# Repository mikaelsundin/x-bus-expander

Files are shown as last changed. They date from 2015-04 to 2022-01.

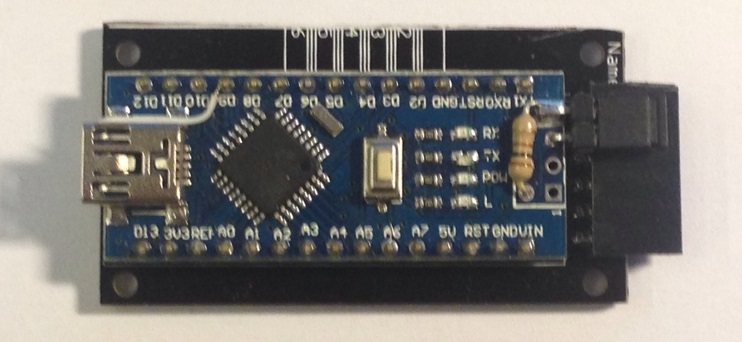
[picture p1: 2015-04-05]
cad/arduion-nano-with-modifications.jpg

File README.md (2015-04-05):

# x-bus-expander
Emulated Model Train digital interface for getting upto 64-inputs and 64-outputs.

Setup the interface
======
* Solder everything.
* Connect up to four boards in a chain.
* Modify dip switches so every board have a unique combination.
* Connect USB-cable to PC and install CH340G driver.

How to connect Inputs
======
Switches can be connected to IN1 or IN2, pull-up is located on-board. 
The input signals must be electrical isolated from the rest of the system to not dammage anything.
If other devices that switches will be connected a optocoupler is suggested to electrical isolate the input.
C1-C8, C10-C17 is to avoid interface from inputs.

How to connect Outputs
======
Led:s / lamps can be connected to OUT1 and OUT2. The output voltage is equal to the VIN voltage.
With 2N7002 the maximum load current is 115mA and suggested voltage shall be 24V DC or less on VIN.
Remember to use correct polarity on VIN, marked with + and - on PCB.

How to use the interface
======
If you are running Freiwald TrainController (www.freiwald.com)
 choose "Lenz Digital Plus / LI100(F)" and correct com-port.
 The outputs will be named with Address 1-64
 The inputs will be named with Address 1-8 and Input 1-8

Hardware modification to Arduino nano:
======
UART signal CTS is attached to D9 (easiest done to clones with CH340G USB chip).
A jumper with 120R resistor to disable auto-reset feature is also added.

Hardware
======
The hardware is adapted to fit a single 10x5cm board.
Suggested manufacture is iteadstudio.com or elecrow.com
The PCB must be separated into two parts after manufacture.
Use a hacksaw for example if PCB tickness is 1.6mm. 
If running at 1.2mm the PCB can acually be cut by a ordinary scissors (the scissors will loose sharpness).

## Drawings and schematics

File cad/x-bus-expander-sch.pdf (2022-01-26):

# 16 Input, 16 Sink Output

A

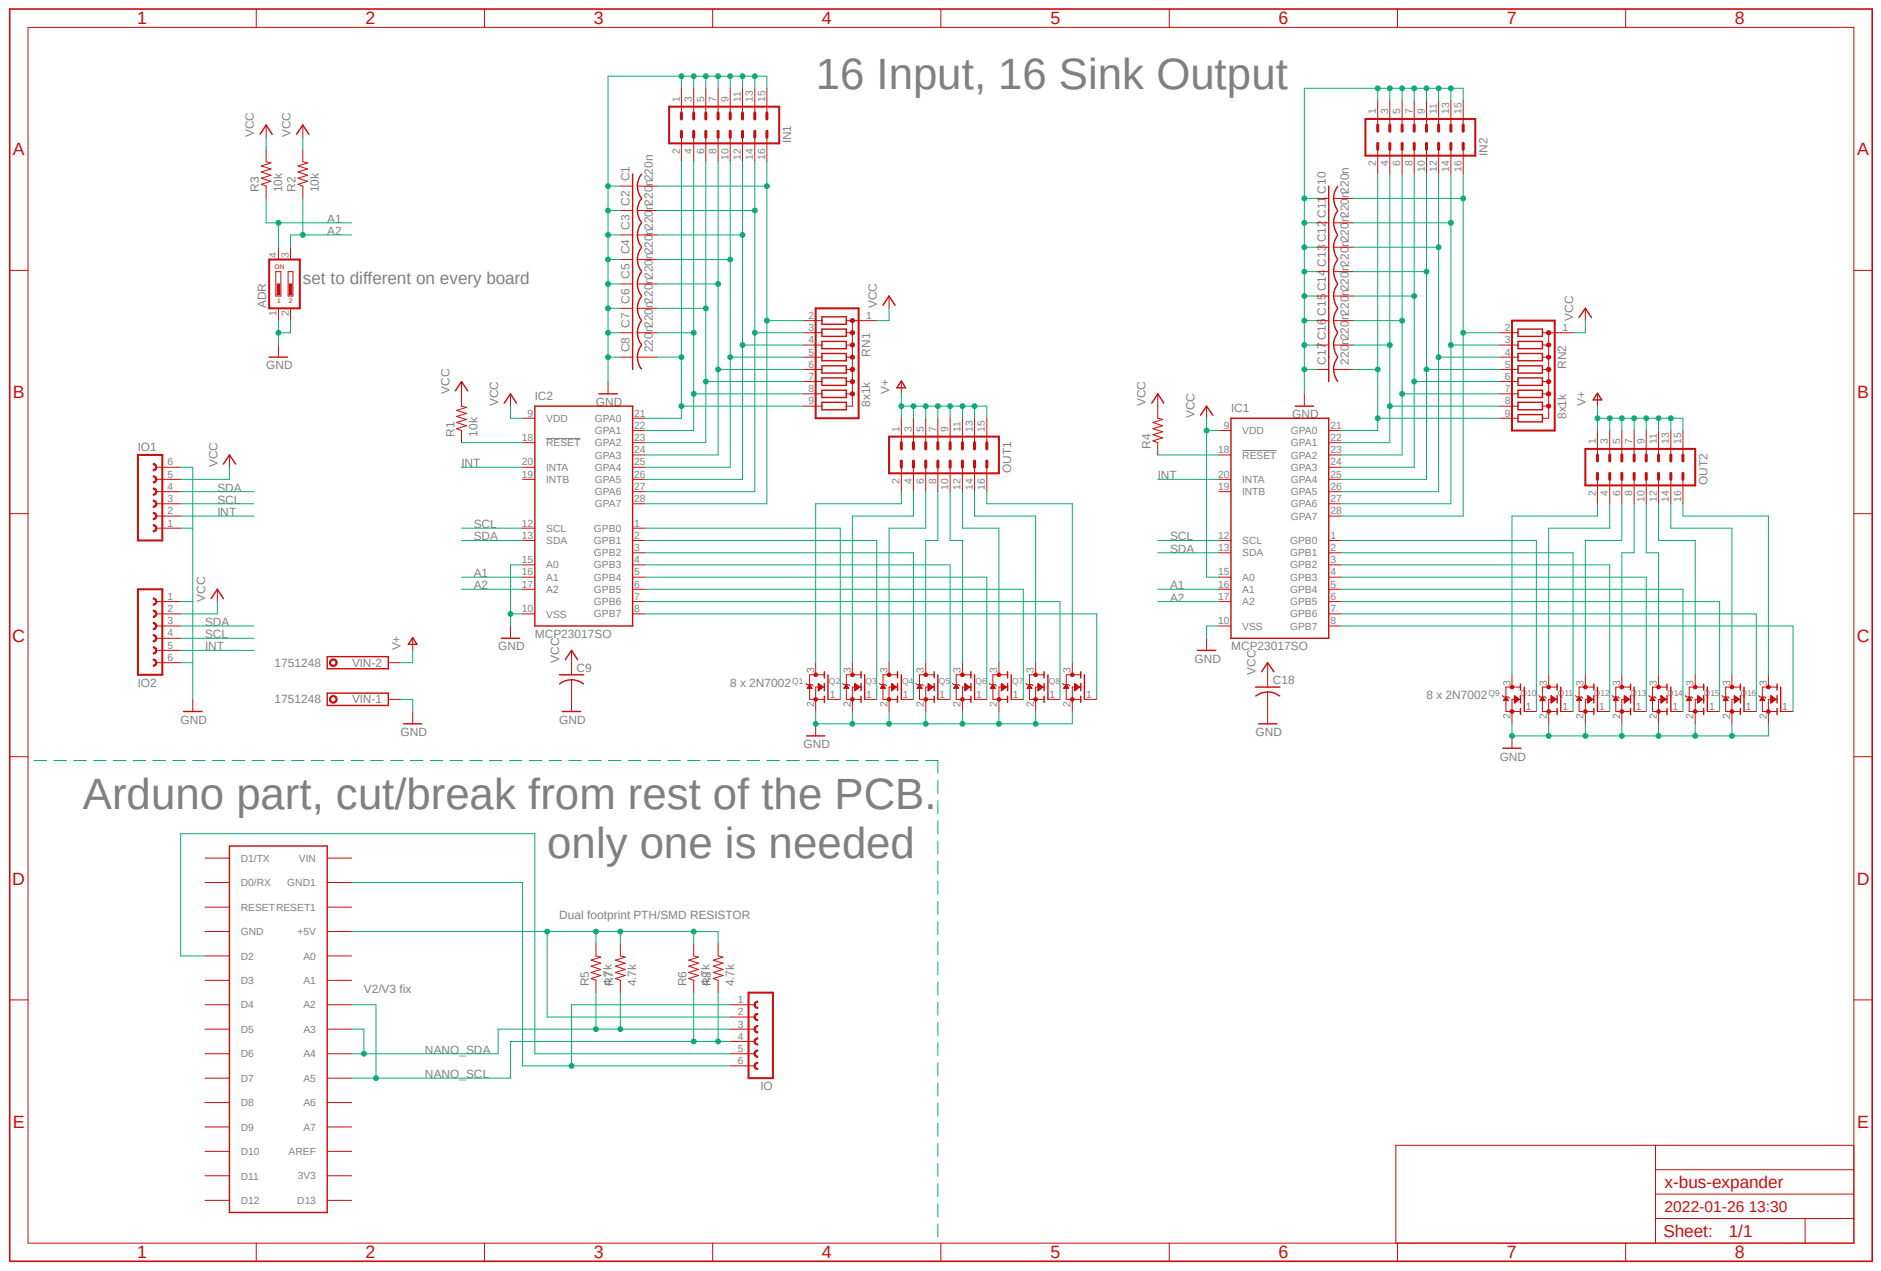
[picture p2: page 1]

9 RN¹ C¹ C² C³ C⁴ C⁵ C⁶ C⁷ C⁸

9 RN² C¹⁰ C¹¹ C¹² C¹³ C¹⁴ C¹⁵ C¹⁶ C¹⁷

set to different on every board

Arduno part, cut/break from rest of the PCB.

only one is needed

Dual footprint PTH/SMD RESISTOR

V2/V3 fix

NANO_SCL | | 6

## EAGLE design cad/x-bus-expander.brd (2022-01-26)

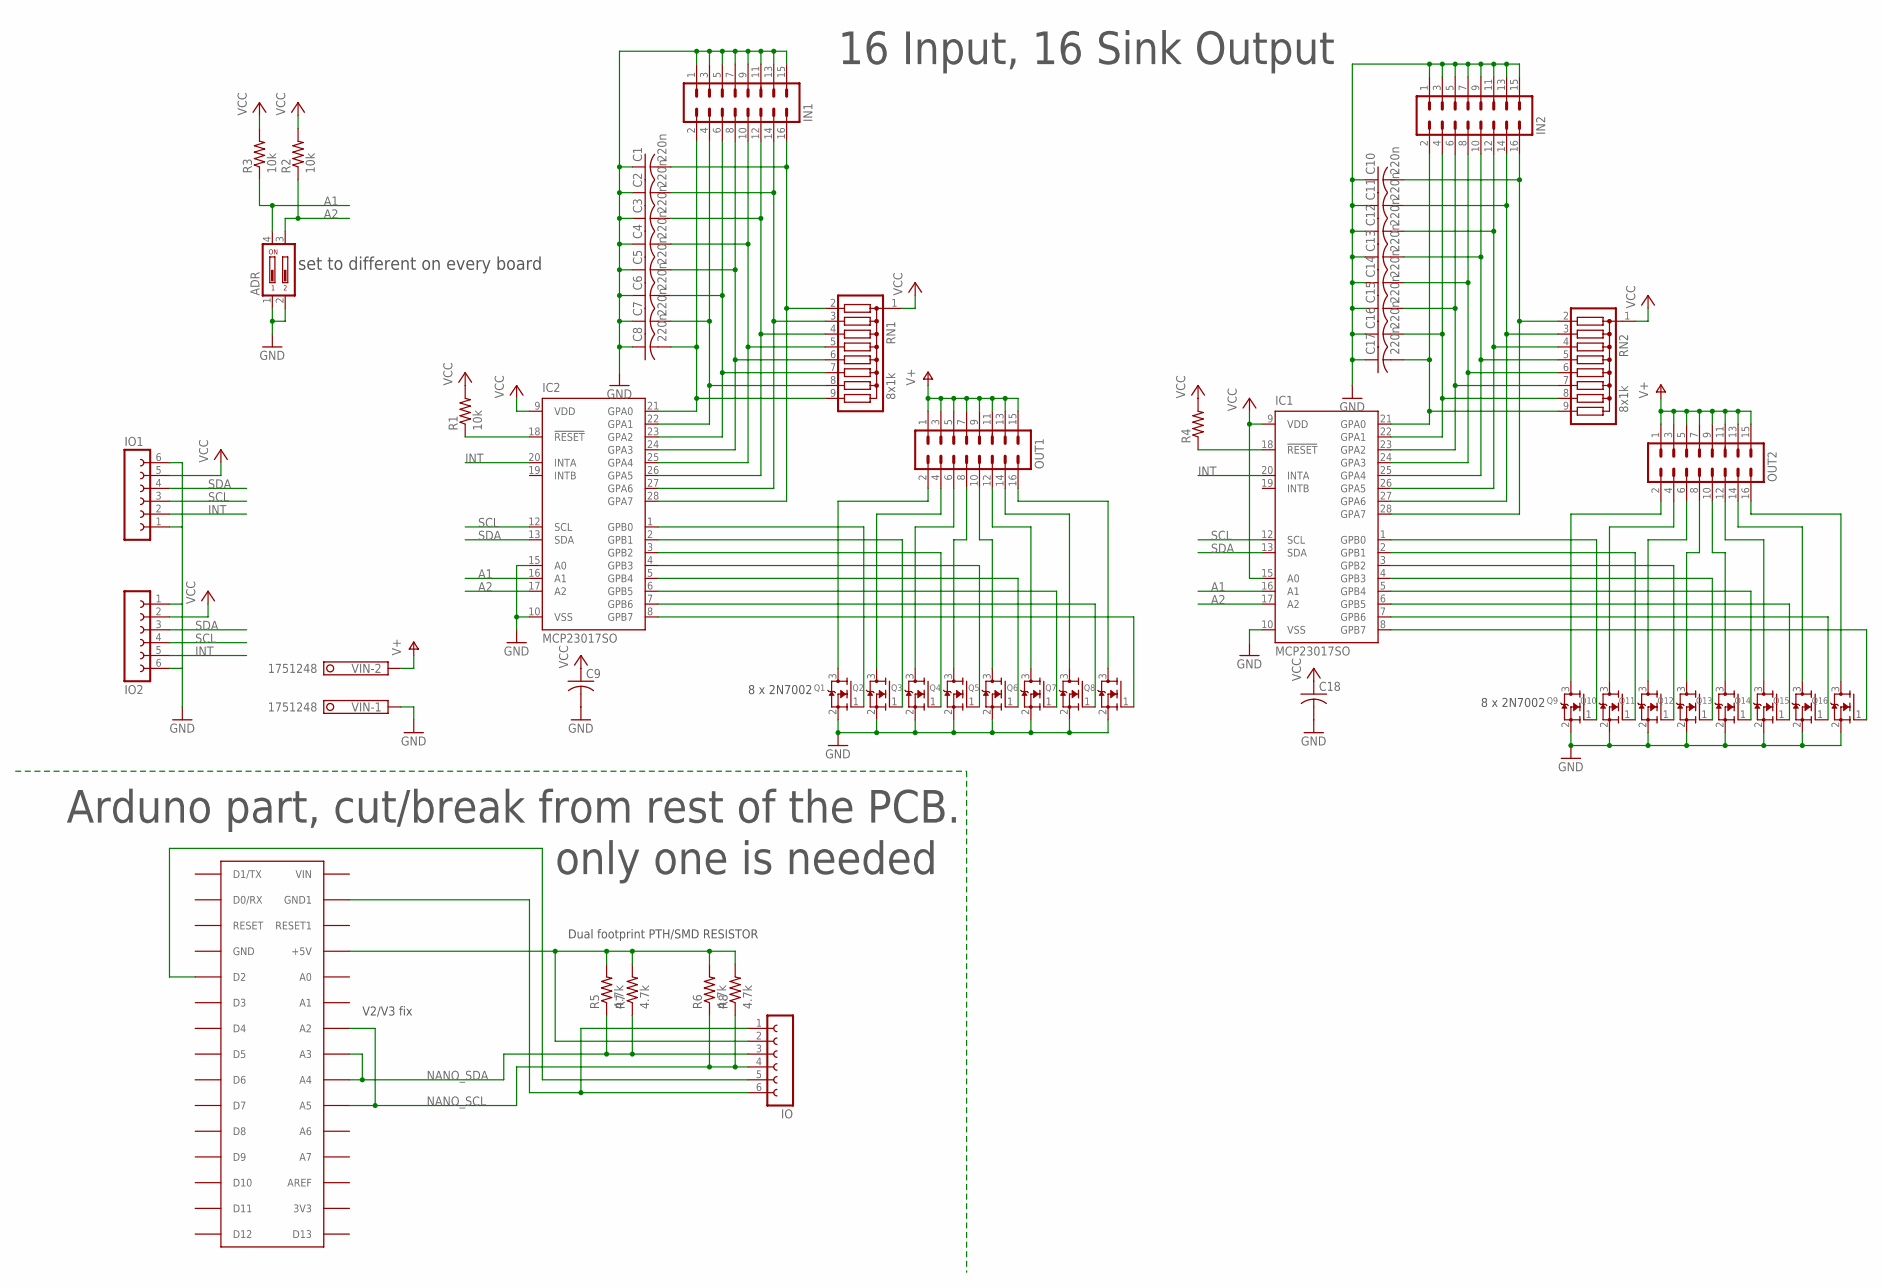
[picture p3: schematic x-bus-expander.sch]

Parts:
ADR: DIP02YL
C1, C2, C3, C4, C5, C6, C7, C8, C10, C11, C12, C13, C14, C15, C16, C17: 220n; C0805
C9, C18: C-USC0805; C0805
IC1, IC2: MCP23017SO; SO28W
IN1, IN2: ML16
IO, IO1, IO2: FE06W
OUT1, OUT2: ML16
Q1, Q2, Q3, Q4, Q5, Q6, Q7, Q8, Q9, Q10, Q11, Q12, Q13, Q14, Q15, Q16: MOSFET-NREFLOW; SOT23
R1, R2, R3: 10k; R0603
R4: R-US_R0603; R0603
R5, R6: 4.7k; 0309/10
R7, R8: 4.7k; R0603
RN1, RN2: 8x1k; SIL9
U$1: ARDUINONANO; PDIP-32
VIN: 1751248

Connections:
A1: ADR.4, IC1.16 (A1), IC2.16 (A1), R3.1
A2: ADR.3, IC1.17 (A2), IC2.17 (A2), R2.1
GND: ADR.1, ADR.2, C1.1, C2.1, C3.1, C4.1, C5.1, C6.1, C7.1, C8.1, C9.2, C10.1, C11.1, C12.1, C13.1, C14.1, C15.1, C16.1, C17.1, C18.2, IC1.10 (VSS), IC2.10 (VSS), IC2.15 (A0), IN1.1, IN1.3, IN1.5, IN1.7, IN1.9, IN1.11, IN1.13, IN1.15, IN2.1, IN2.3, IN2.5, IN2.7, IN2.9, IN2.11, IN2.13, IN2.15, IO1.1, IO1.6, IO2.1, IO2.6, Q1.2 (S), Q2.2 (S), Q3.2 (S), Q4.2 (S), Q5.2 (S), Q6.2 (S), Q7.2 (S), Q8.2 (S), Q9.2 (S), Q10.2 (S), Q11.2 (S), Q12.2 (S), Q13.2 (S), Q14.2 (S), Q15.2 (S), Q16.2 (S), VIN.1
INT: IC1.20 (INTA), IC2.20 (INTA), IO1.2, IO2.5
unnamed: OUT1.2, Q1.3 (D)
unnamed: OUT1.4, Q2.3 (D)
unnamed: OUT1.6, Q3.3 (D)
unnamed: OUT1.8, Q4.3 (D)
unnamed: OUT1.10, Q5.3 (D)
unnamed: OUT1.12, Q6.3 (D)
unnamed: OUT1.14, Q7.3 (D)
unnamed: OUT1.16, Q8.3 (D)
unnamed: IC2.1 (GPB0), Q1.1 (G)
unnamed: IC2.2 (GPB1), Q2.1 (G)
unnamed: IC2.3 (GPB2), Q3.1 (G)
unnamed: IC2.4 (GPB3), Q4.1 (G)
unnamed: IC2.5 (GPB4), Q5.1 (G)
unnamed: IC2.6 (GPB5), Q6.1 (G)
unnamed: IC2.7 (GPB6), Q7.1 (G)
unnamed: IC2.8 (GPB7), Q8.1 (G)
unnamed: C8.2, IC2.21 (GPA0), IN1.2, RN1.9
unnamed: C7.2, IC2.22 (GPA1), IN1.4, RN1.8
unnamed: C6.2, IC2.23 (GPA2), IN1.6, RN1.7
unnamed: C5.2, IC2.24 (GPA3), IN1.8, RN1.6
unnamed: C4.2, IC2.25 (GPA4), IN1.10, RN1.5
unnamed: C3.2, IC2.26 (GPA5), IN1.12, RN1.4
unnamed: C2.2, IC2.27 (GPA6), IN1.14, RN1.3
unnamed: C1.2, IC2.28 (GPA7), IN1.16, RN1.2
unnamed: IC2.18 (!RESET), R1.1
unnamed: OUT2.2, Q9.3 (D)
unnamed: OUT2.4, Q10.3 (D)
unnamed: OUT2.6, Q11.3 (D)
unnamed: OUT2.8, Q12.3 (D)
unnamed: OUT2.10, Q13.3 (D)
unnamed: OUT2.12, Q14.3 (D)
unnamed: OUT2.14, Q15.3 (D)
unnamed: OUT2.16, Q16.3 (D)
unnamed: IC1.1 (GPB0), Q9.1 (G)
unnamed: IC1.2 (GPB1), Q10.1 (G)
unnamed: IC1.3 (GPB2), Q11.1 (G)
unnamed: IC1.4 (GPB3), Q12.1 (G)
unnamed: IC1.5 (GPB4), Q13.1 (G)
unnamed: IC1.6 (GPB5), Q14.1 (G)
unnamed: IC1.7 (GPB6), Q15.1 (G)
unnamed: IC1.8 (GPB7), Q16.1 (G)
unnamed: C17.2, IC1.21 (GPA0), IN2.2, RN2.9
unnamed: C16.2, IC1.22 (GPA1), IN2.4, RN2.8
unnamed: C15.2, IC1.23 (GPA2), IN2.6, RN2.7
unnamed: C14.2, IC1.24 (GPA3), IN2.8, RN2.6
unnamed: C13.2, IC1.25 (GPA4), IN2.10, RN2.5
unnamed: C12.2, IC1.26 (GPA5), IN2.12, RN2.4
unnamed: C11.2, IC1.27 (GPA6), IN2.14, RN2.3
unnamed: C10.2, IC1.28 (GPA7), IN2.16, RN2.2
unnamed: IC1.18 (!RESET), R4.1
unnamed: IO.5, U$1.D2
unnamed: IO.1, IO.6, U$1.GND1
unnamed: IO.2, R5.2, R6.2, R7.2, R8.2, U$1.+5V
NANO_SCL: IO.4, R6.1, R8.1, U$1.A2, U$1.A5
NANO_SDA: IO.3, R5.1, R7.1, U$1.A3, U$1.A4
SCL: IC1.12 (SCL), IC2.12 (SCL), IO1.3, IO2.4
SDA: IC1.13 (SDA), IC2.13 (SDA), IO1.4, IO2.3
V+: OUT1.1, OUT1.3, OUT1.5, OUT1.7, OUT1.9, OUT1.11, OUT1.13, OUT1.15, OUT2.1, OUT2.3, OUT2.5, OUT2.7, OUT2.9, OUT2.11, OUT2.13, OUT2.15, VIN.2
VCC: C9.1, C18.1, IC1.9 (VDD), IC1.15 (A0), IC2.9 (VDD), IO1.5, IO2.2, R1.2, R2.2, R3.2, R4.2, RN1.1, RN2.1

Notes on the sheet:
Dual footprint PTH/SMD RESISTOR
8 x 2N7002
V2/V3 fix
16 Input, 16 Sink Output
Arduno part, cut/break from rest of the PCB.
only one is needed
set to different on every board

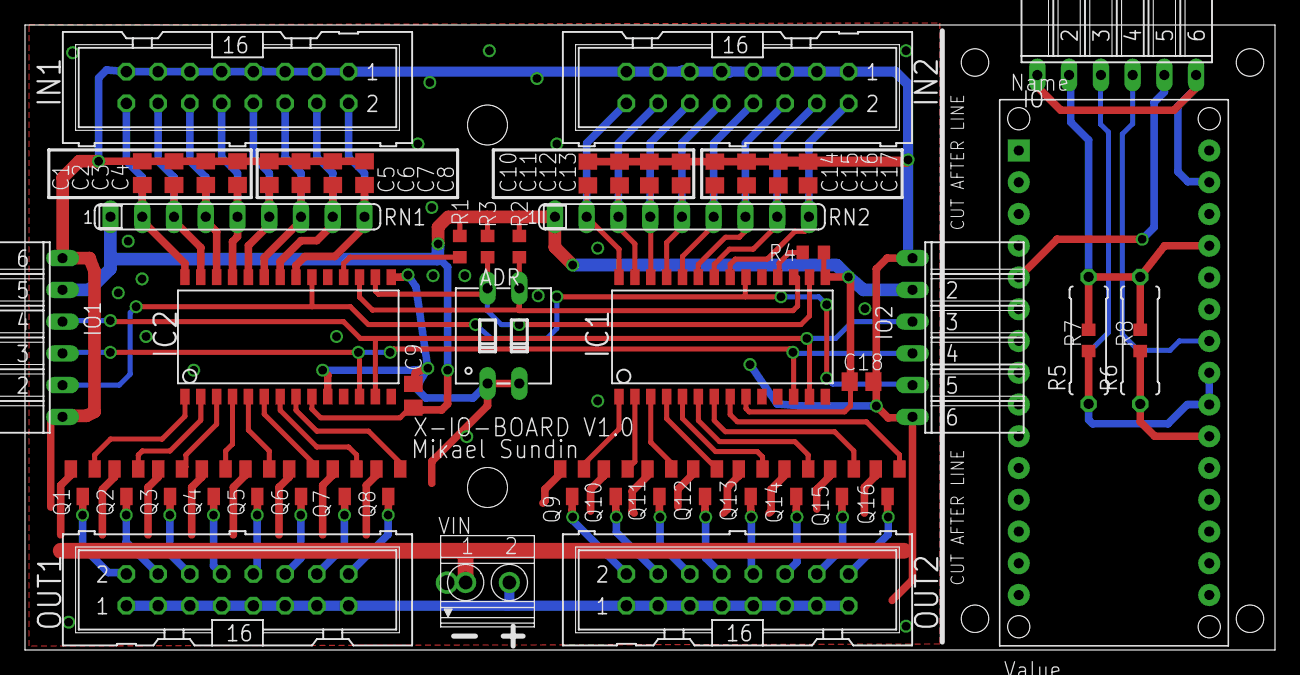
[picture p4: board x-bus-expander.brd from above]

Board: 2 copper layers, 100.0 x 50.0 mm, 56 parts (0 on the bottom side), 63 nets.

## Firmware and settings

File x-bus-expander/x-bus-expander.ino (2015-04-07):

/******************************************************************************
Copyright (c) 2015, Mikael Sundin
All rights reserved.

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
******************************************************************************/

#include <arduino.h>
#include "xbushost.h"

#define LED_PIN  13
#define CTS_PIN  9

xBusHost xbus = xBusHost();

#define NBR_OF_OUTPUTS  8
uint8_t output[NBR_OF_OUTPUTS];

uint8_t read_button(){
  uint8_t tmp=0;
  
  
  tmp |= digitalRead(3) ? 0x00 : 0x01;
  tmp |= digitalRead(4) ? 0x00 : 0x02;
  tmp |= digitalRead(5) ? 0x00 : 0x04;
  tmp |= digitalRead(6) ? 0x00 : 0x08;
  
  return tmp;
}


void setup(){
  pinMode(3, INPUT_PULLUP);
  pinMode(4, INPUT_PULLUP);
  pinMode(5, INPUT_PULLUP);
  pinMode(6, INPUT_PULLUP);
  
  pinMode(LED_PIN, OUTPUT);
  xbus.begin(Serial, CTS_PIN);
}

void loop(){
  xbus.update();
  
  //todo: add reading from i2c bus
  xbus.set_feedback(0, output[0]);
  xbus.set_feedback(1, output[1]);
  xbus.set_feedback(2, read_button());
}

void notify_xbus_accessory_decoder_activated( uint8_t board, uint8_t board_output, uint8_t dir){
  if(board < NBR_OF_OUTPUTS){ 
    if(dir){
      output[board] |= (1<<board_output);
    }else{
      output[board] &= ~(1<<board_output);
    }
  }
}

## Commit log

2015-04-05 First upload, only test for now.
    [x-bus-expander.brd, x-bus-expander.sch]
2015-04-05 Fixed a pcb bug when Arduion nano v2/v3 have different I2C pins placement.
    [x-bus-expander.brd, x-bus-expander.sch]
2015-04-14 Added a MCP23017 driver and fixed connection between xbus and the MCP chips.
    [MCP23017.cpp]
2022-01-26 Updated schematic with some information and generated pdf for schematic.
    [x-bus-expander.brd, x-bus-expander.sch]
